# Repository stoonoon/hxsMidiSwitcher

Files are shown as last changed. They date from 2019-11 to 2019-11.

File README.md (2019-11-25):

# hxsMidiSwitcher
Simple 8 button MIDI controller for Line 6 HX Stomp using Nano clone

I'd originally shared this at https://www.basschat.co.uk/topic/338238-build-your-own-midi-controller-i-did/ but it's been pointed out (Thanks Josh!) that this would be a more sensible place for it.

It works OK and has served me fairly well over the last ~8 months I've been using it, but v2 is in the works with a touchscreen and expression pedal input...

Basic description (from that thread - although there's more info there if you want to trawl through the entire thread...

I wanted to add some more control options to my Stomp and was looking at controllers like the Morningstar MC6, but couldn't justify the £200 outlay.. so looked into making one myself - and it's turned out to be far easier and cheaper than I expected.

Total cost for all the electronics and switches is about £25 -30 depending on how confident you are at slightly fiddly soldering... the extra few quid gets you a pre-soldered microcontroller and an adaptor board with screw terminals, so the only soldering you'd need to do is for the wires to the tags on the footswitches and on the MIDI socket.

And then you'll need something to house it in. I made a 3d printed enclosure for mine, but any box you can buy/build/modify will do.

If anyone's interested in making something similar for themselves, I'd be happy to share wiring diagrams and the code I used. I'm no electronic engineer or programmer, so no doubt there's plenty of room for improvement, but I've got it to work well enough to do what I need it to, and maybe it'll work for you too? I'm happy to help with tweaking it for slightly different configurations if you'd want a different layout.

What it does:

You press a footswitch, and it sends a MIDI message. The way I have mine setup is that it either sends a MIDI PC (Program Change) message to change preset patch on my HX stomp, or a MIDI CC (Control Change) message to change any of a number of other settings or parameters. It could potentially send MIDI notes as well if you wanted to use it as a pedal keyboard to play a synth with, I suppose.

If you hold a footswitch down, it can send a different MIDI message (I only use this for activating the tuner by holding the tap tempo button so far, but it could be setup for any of the switches)

If you press more than one footswitch down at once, it can do something else again depending on which ones you press. Mine is set so that pressing 1+2 or 2+3 switches through different pages / banks of button configurations, and pressing 7 + 8 is a sort of panic mode which resets the HX stomp to preset 1, and resets the controller back to the first page.

What it can't do:

It's not programmable from the unit. To change the way the buttons are configured you need to tweak the code and then re-upload it. There's probably a more elegant way to deal with this, but it works well enough for me as is - I don't expect to need to reconfigure it very often once I've got it set up.

Right - I'm gonna stop there for now.... if no-one's interested then I'm just rambling into the void for nowt. If anyone is interested though, let us know and I can post more details. Or, if you know more than me and can spot where I've gone wrong or what I should have done better - lemme know and I'll try and improve it!

Cheers,

stoo

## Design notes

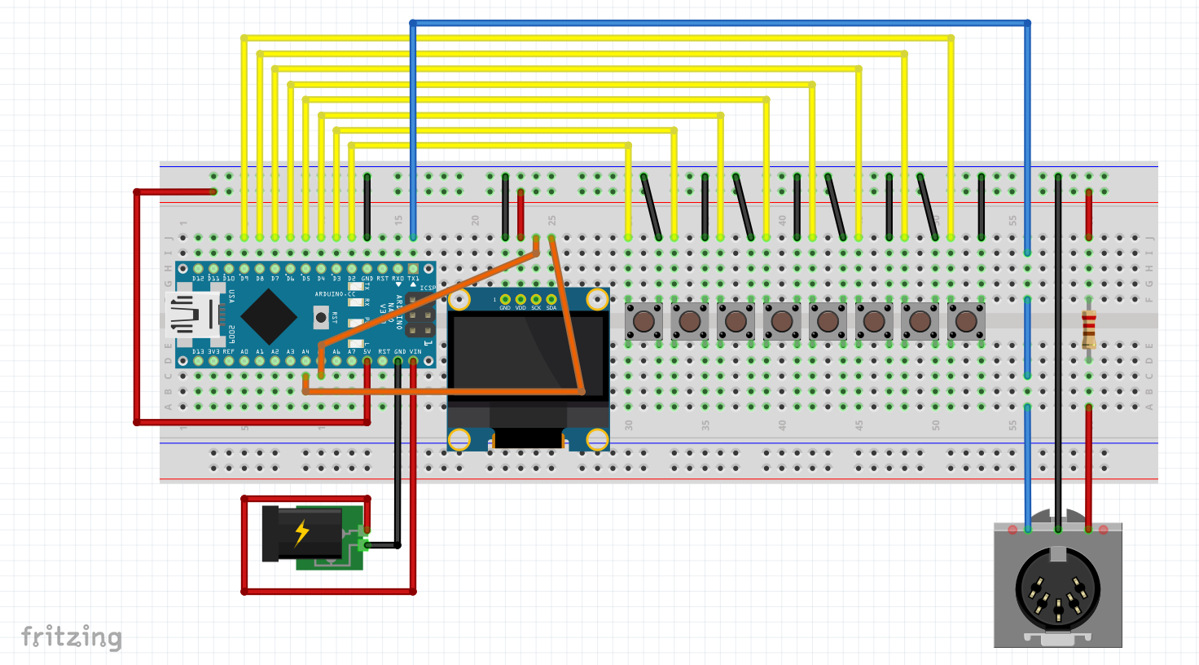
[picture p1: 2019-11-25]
breadboard.png

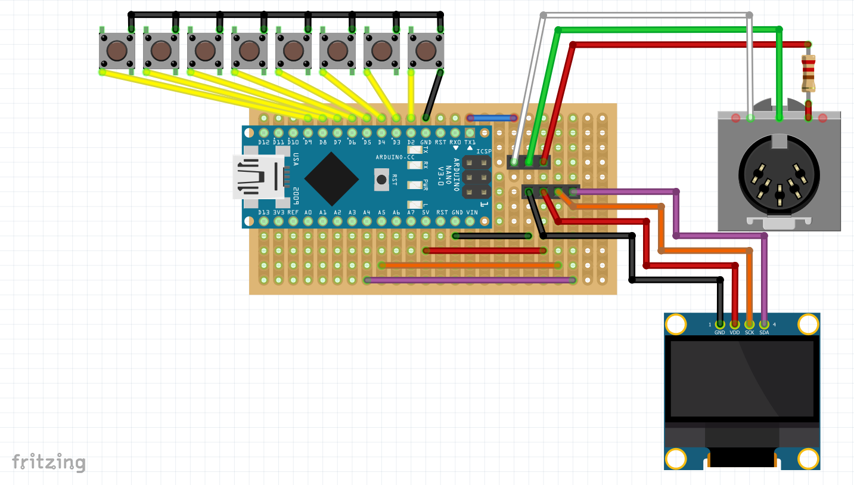
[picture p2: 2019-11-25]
stripboard.png

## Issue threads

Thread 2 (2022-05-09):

Long Press action missing?

gobbersbubbus, 2022-05-09:
Hey @stoonoon!

I was building this switcher and I don't have the function to long press the tap tempo to access the tuner?

I dont have the display so im not sure if I am missing it there, but do you have the code that allows the long press to work?

I think you can access it by pushing multiple buttons butI would prefer to have it as the long press on the tuner?

Do you have the code for that and where to drop in?

Thank you!

stoonoon, 2022-05-09:
I'm fairly sure it used to work - but at the moment I'm just on my phone and trying to reacquaint myself with years old code is a bit of a challenge....
It looks like it's at least part there, so my best guess at the moment would be that at some point I redesigned my menu page layout and missed off the case statements for long presses.... I think it's setup so case 0 to 7 were single short press actions and 8 to 15 would be long press.
Hopefully that should be enough to get you started.... If not, let us know and I'll see what I can work out when I'm next at a desktop

gobbersbubbus, 2022-05-09:
WOW THAT WAS FAST. I fully planned on waiting a week to hear from you!

That is promising, I can try to look at it, but I’m almost looking at hieroglyphics here ha ha.

This is for the Arduino Nano which I believe only has 12 digital pins? Does that mean pins 0-7 are single short press and 8-12 would be long press?

(I’m so sorry if this is a dumb question…)

Thank you

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

stoonoon, 2022-05-09:
The number for "nextCommand" isn't directly linked to the pin number on the Arduino. It's just an arbitrary variable that acts as a menu of possible midi actions... 0 to 7 on that list do happen to map to the footswitches - and they are used for the short press actions for each one. If a long press is detected, the readButtons function sets the nextCommand variable to (pin number + number of switches)... And so long presses would use the next 8 options in the "menu". Hope that makes sense.

If you look at line 311-313 you'll see:
case 7:
          MIDI.sendControlChange(53,0,1); //FS5
          break;

If you add an extra 3 lines immediately after those but instead with :

case 8:
          MIDI.sendControlChange(68,68,1); //tuner
          break;

I think that might do it....

gobbersbubbus, 2022-05-10:
I think I understand, thank you!

Sorry, last question, if I wanted to add a long press function to FS4 or FS5, where would I input those midi cc codes? Of is that possible?

Thank you!

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

stoonoon, 2022-05-10:
Do you mean long press the 4th/5th switch on your switcher?
just add another 3 lines like before but with the first line being "case 11:" for FS4 long press or "case 12:" for FS5 long press....
so, for example:

case 11: //<- this bit signifies a long press on the 4th switch
  MIDI.sendControlChange(69,9,1); //<- this is the command for previous snapshot
  break; // <- this just signifies the end of the "case" statement

case 12: // < - this bit signifies switch a long press on the 5th switch
  MIDI.sendControlChange(69,8,1); // < - this is the command for next snapshot
  break;

or did you mean to be able to use FS4 and FS5 on the stomp? In which case you could use:

case 4: // <- this means a short press on the 5th switch
  MIDI.sendControlChange(52,0,1); // <- this is the command for FS4 on the stomp
  break;

case 5: // <- this means a short press on the 6th switch
  MIDI.sendControlChange(53,0,1); // <- this is the command for FS5 on the stomp
  break;

Does that help?

stoonoon, 2022-05-25:
> Hey Stoo! I really appreciate your help with all of this! I had one more question if you had a moment… Would you have the code to add a potentiometer/expression pedal to this code? I appreciate it!

Sorry - that's not something I ever implemented on this version. I did start to add one on my other switcher - https://github.com/stoonoon/hxsMidiSwitchTouch - it was working at one point, but now mine doesn't.... I suspect it's a wiring issue, but never found it useful enough to be too bothered about troubleshooting it.

If you wanted to have a go at implementing it yourself, I *think* you might be able to get away with pasting in the "byte readPedalPos()" and "void readExpPedalCC()" functions from 07_exp_pedal.ino into your code
and then add the "readExpPedalCC();" line from 11_loop.ino into your "void loop()" function

Then you'd also need any relevant variable declarations too - should be either from the top of 08_exp_pedal.ino or from 02_globals.ino

gobbersbubbus, 2022-05-25:
You’re insane Stoo, so knowledgeable!

Okay, final question and I stop persevering you. My pot does not flow 0-100%, or 0-127, it goes from 0-100% at about 10%…

In your description I see you have a unique volume pedal and I should be able to “simplify the mapping from R2 to pd1 as they should rise proportionally to each other through the full extent of any travel…”

Would this be just adjusting the buffer value or am I way off?

Again, thank you so much!

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

stoonoon, 2022-05-25:
If you've got a linear pot which sends 0.0V for off/heeldown and 5.0V for on/toedown, then I would try replacing the readPedalPos() function with something like this:

byte readPedalPos() {
  int raw = analogRead(analogExpressionPedalPin); // get pedal position input (range 0 to 1023)
  if (raw) { // got some pedal position reading
    float pdl;
    pdl = mapf(raw, 0, 1023, 0, 127); // map pedal position into a 0-127 range for MIDI
    return byte(pdl);
  } // if(raw)
  else return 0; // no pedal position reading returned - assume heel down
}// byte readPedalPos()

Might need to add some deadzone compensation in later but hopefully that'll be closer to what you need?

gobbersbubbus, 2022-05-25:
I will monkey with it, thanks Stoo!!!!

gobbersbubbus, 2022-12-06:
Hey Stoo!Question, in your V1 code, is it possible to do a three button press? How would one code that in this?Thank you!On May 25, 2022, at 3:29 PM, Stuart Noon ***@***.***> wrote:
If you've got a linear pot which sends 0.0V for off/heeldown and 5.0V for on/toedown, then I would try replacing the readPedalPos() function with something like this:
byte readPedalPos() {
int raw = analogRead(analogExpressionPedalPin); // get pedal position input (range 0 to 1023)
if (raw) { // got some pedal position reading
float pdl;
pdl = mapf(raw, 0, 1023, 0, 127); // map pedal position into a 0-127 range for MIDI
return byte(pdl);
} // if(raw)
else return 0; // no pedal position reading returned - assume heel down
}// byte readPedalPos()
Might need to add some deadzone compensation in later but hopefully that'll be closer to what you need?

—Reply to this email directly, view it on GitHub, or unsubscribe.You are receiving this because you authored the thread.Message ID: ***@***.***>

stoonoon, 2022-12-06:
> Hey Stoo!Question, in your V1 code, is it possible to do a three button press? How would one code that in this?Thank you!

I'm honestly not sure. It wasn't something I'd considered at the time, but there is a small chance it just might work. That said - I'd be surprised if it worked reliably....

If you wanted to give it a try, the part that looks for mutiple button presses is in the readButtons() function in hxsMidiSwitcher.ino from line 157

You could try changing the part that goes

```
else if ( switchPressed[6] && switchPressed[7]) { // last two switches - reset to page 0 and patch 0
        nextCommand = pagePatchReset;
        currentPage = 0;
      }
```

to

```
else if ( switchPressed[5] && switchPressed[6] && switchPressed[7]) { // last three switches - reset to page 0 and patch 0
        nextCommand = pagePatchReset;
        currentPage = 0;
      }
```

and see how you get on. My hunch would be that if you also have 2-button combos set up for any 2 of the buttons in your 3-button combo, then you'd probably get the 2-button combo detected and the 3-button one ignored a lot of the time.
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
stoonoon, 2023-05-15:
> Your questions are my questions as well! HahaWell I appreciate your time and understand not tackling it. I’ll see what I can do! Thank you!On May 15, 2023, at 12:36 PM, Stuart Noon ***@***.***> wrote:

Good luck!

gobbersbubbus, 2024-03-29:
Hey Stoo!I had another question about the code. Would it be possible to have a way the switch behave as a toggle? For example, have one push button trigger a control change of 1 sending “velocity” of 127 then the second press send the “velocity” of 0? How would that be implemented in the code?Thank you!-Preston On May 15, 2023, at 12:47 PM, Stuart Noon ***@***.***> wrote:

Your questions are my questions as well! HahaWell I appreciate your time and understand not tackling it. I’ll see what I can do! Thank you!On May 15, 2023, at 12:36 PM, Stuart Noon @.***> wrote:

Good luck!

—Reply to this email directly, view it on GitHub, or unsubscribe.You are receiving this because you modified the open/close state.Message ID: ***@***.***>

stoonoon, 2024-03-30:
> Hey Stoo!I had another question about the code. Would it be possible to have a way the switch behave as a toggle? For example, have one push button trigger a control change of 1 sending “velocity” of 127 then the second press send the “velocity” of 0? How would that be implemented in the code?Thank you!-Preston

The button actions are hard coded according to which page you're on, so this would be an awkward one to do easily without some significant changes.

One possible workaround - if you can make do with only one toggle type button, then you could create two pages that are the same except for button x on the first page has its action in the midiSend function set to CC send with a value of 127 and then also change the menu page to 2.

On menu page 2, the action would need to be reversed so that it sends the CC value as zero and then sets the menu page pack to 1.

stoonoon, 2024-03-30:
> Hey Stoo!I had another question about the code. Would it be possible to have a way the switch behave as a toggle?

Not sure why I didn't think of this earlier, but there's no need to use multiple pages.

Instead of having something like :

case 0:
    MIDI.sendControlChange(49,0,1); //FS1
    break;

you could have something like:

case 0:
    static bool switch0NextActionIsA = true; // this will only set the variable to true on the first time the code gets here
    if (switch0NextActionIsA) { // then we do action "A" for this switch :
        MIDI.sendControlChange(69,0,1); //snapshot 1
        switch0NextActionIsA = false; // use action "B" next time
        }
    else { // then we do action "B" for this switch :
        MIDI.sendControlChange(69,1,1); //snapshot 2
        switch0NextActionIsA = true; // use action "A" next time
        }
    break;

gobbersbubbus, 2024-03-30:
Thanks for the fast response! I’ll throw it in and tinker with it!On Mar 30, 2024, at 9:22 AM, Stuart Noon ***@***.***> wrote:

Hey Stoo!I had another question about the code. Would it be possible to have a way the switch behave as a toggle?

Not sure why I didn't think of this earlier, but there's no need to use multiple pages.
Instead of having something like :
case 0:
MIDI.sendControlChange(49,0,1); //FS1
break;
you could have something like:
case 0:
static bool switch0NextActionIsA = true; // this will only set the variable to true on the first time the code gets here
if (switch0NextActionIsA) { // then we do action "A" for this switch :
MIDI.sendControlChange(69,0,1); //snapshot 1
switch0NextActionIsA = false; // use action "B" next time
}
else { // then we do action "B" for this switch :
MIDI.sendControlChange(69,1,1); //snapshot 2
switch0NextActionIsA = true; // use action "A" next time
}
break;

—Reply to this email directly, view it on GitHub, or unsubscribe.You are receiving this because you modified the open/close state.Message ID: ***@***.***>

Closed 2022-05-25.

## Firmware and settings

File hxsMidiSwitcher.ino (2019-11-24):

/*
 * ---------------------------------------------------
 * 
 * Simple 8 button MIDI controller for Line 6 HX Stomp using Nano clone
 * 
 * MIDI connectivity based on https://www.instructables.com/id/Send-and-Receive-MIDI-with-Arduino/
 * MIDI pin 4 to TX1
 * 
 * 128x64 I2C OLED - the one I used was https://smile.amazon.co.uk/gp/product/B076PL474K
 * SDA to A4
 * SCL to A5
 * 
 * 8x momentary SPST switches connected between GND and D2 - D9
 * 
 * ---------------------------------------------------
 */



#include <MIDI.h>
#include <SPI.h>
#include <Wire.h>
#include <Adafruit_GFX.h>
#include <Adafruit_SSD1306.h>


// Declaration for an SSD1306 display connected to I2C (SDA, SCL pins)
#define SCREEN_WIDTH 128 // OLED display width, in pixels
#define SCREEN_HEIGHT 64 // OLED display height, in pixels
#define OLED_RESET     -1 // Reset pin # ((was 4) or -1 if sharing Arduino reset pin)
#define OLED_ADDR 0x3C  // address of my 128x64 OLED
Adafruit_SSD1306 display(SCREEN_WIDTH, SCREEN_HEIGHT, &Wire, OLED_RESET);

// error blink codes
#define ERR_DISP_ALLOC 3 // display allocation error

static const unsigned ledPin = LED_BUILTIN; // use onboard LED as activity indicator
static const byte switchPin[] = {2,3,4,5,6,7,8,9}; // pins for footswitch inputs
static const byte switchCount = 8; // number of footswitches used
static bool switchPressed[switchCount]; // current state of footswitches
static bool switchLastState[switchCount]; //previous state of footswitches (used for long press detection)
static unsigned long lastPressMillis[switchCount]; // when the last button press was detected
static unsigned long lastReleaseMillis[switchCount]; // when the last button was released

// Created and binds the MIDI interface to the default hardware Serial port
MIDI_CREATE_DEFAULT_INSTANCE();


void errBlink(int errCode) {
  byte blinkTime = 200; // duration for each blink
  byte blinkGap = 200; // gap between each blink
  int burstWait = 1000; // wait time between bursts 
  for (;;) { // loop forever
    for (int i = 1; i <= errCode; i++) {
      digitalWrite(ledPin,HIGH);
      delay(blinkTime);
      digitalWrite(ledPin,LOW);
      delay(blinkGap);
    }
    delay(burstWait);
  }
} // end of errBlink()


void setup() {
  pinMode(ledPin, OUTPUT);  // setup activity LED pin for output

  MIDI.begin(MIDI_CHANNEL_OMNI);  // Listen to all incoming messages
  
 // SSD1306_SWITCHCAPVCC = generate display voltage from 3.3V internally
 if(!display.begin(SSD1306_SWITCHCAPVCC, OLED_ADDR)) { // Address 0x3C for my 128x64 variant
   errBlink(ERR_DISP_ALLOC);
  }

  // Show initial display buffer contents on the screen --
  // the library initializes this with an Adafruit splash screen.
  display.display();
  delay(500); // Pause for 0.5 seconds
  display.setTextSize(1);      // Normal 1:1 pixel scale
  display.setTextColor(WHITE); // Draw white text
  display.setCursor(0, 0);     // Start at top-left corner
  display.cp437(true);         // Use full 256 char 'Code Page 437' font
  display.clearDisplay();
  
  // Initialise switches and related variable arrays
  for (int i=0;i<switchCount;i++) { 
    pinMode(switchPin[i], INPUT_PULLUP); // add pullup resistors to all footswitch input pins
    switchPressed[i] = false; //initialise switch state
    switchLastState[i] = false; //initialse last switch state
    lastReleaseMillis[i] = millis(); // initialise time switch last released
    lastPressMillis[i] = lastPressMillis[i] -1; // initialise time switch last pressed
  }

} // end of setup


void loop() {
  readButtons();
  displayUpdate();
  midiSend();
} // end of loop

/*
 * ----------------------------------------
 * 
 * Input related declarations and functions
 * 
 * ----------------------------------------
 */


static const bool switchDown = LOW; // because we are using pullup resistor and switch to GND
static const byte debounceTime = 20; // after processing a button press, ignore further input for some milliseconds
static const byte debounceDelay = 5; // amount of time to wait before retesting debounceTime
static const int longPressTime = 1000; // how long a switch has to be held to count as a long press
static int switchPressedCounter = 0; // how many switches are currently pressed
static byte nextCommand = -1; // most important pending action - the switch that was last pressed, or other command via multi or long press
static byte lastCommand = -1; // last command sent (used for display confirmation)
static unsigned long commandMillis = millis(); // the time that nextCommand was last set - ie the last switch to be pressed
static const byte pageDnCmd = 5*switchCount + 1;
static const byte pageUpCmd = 5*switchCount + 2; 
static const byte pagePatchReset = 5*switchCount + 3; 
static const byte tunerCmd =  5*switchCount + 4;

static byte currentPage = 0; // the current page / bank to be displayed
static const byte pageCount =1; // how many pages we have configured

void readButtons() {  
  switchPressedCounter = 0;
  for (int i=0;i<switchCount;i++) {
    switchPressed[i] = ( digitalRead(switchPin[i]) == switchDown ); // set array element to true if switch is currently pressed, or false if not
    if (switchPressed[i] != switchLastState[i]) { //potential press or release detected
      if (switchPressed[i]) { // potential new press detected
        if ( millis() > (lastPressMillis[i] + debounceTime) ) { // genuine press and not switch bounce
          lastPressMillis[i] = millis();
          switchLastState[i] = true;
          nextCommand = i;
          commandMillis = millis();          
        }
      }
      else if (!switchPressed[i]) { //potential switch release detected
        if ( millis() > (lastReleaseMillis[i] + debounceTime ) ) { // genuine release and not switch bounce
          lastReleaseMillis[i] = millis();
          switchLastState[i] = false;
        }
      }
    }
    if (switchPressed[i]) {
      switchPressedCounter++;  //increment counter used to check multiple presses      
      if (  millis() > (lastPressMillis[i] + longPressTime)  ) { // long press detected
        lastPressMillis[i] = millis(); // reset timer so it doesn't re-trigger every loop
        nextCommand = i + switchCount; // use the next n numbers as a second bank of commands representing long press actions        
      }
    }
  }
  static bool comboActive = false; // remembers whether multiple presses were detected to avoid re-triggering every loop
  if (switchPressedCounter > 1 ) { // multiple presses detected
    if (!comboActive) {
      comboActive = true;
      if ( switchPressed[0] && switchPressed[1]) { // first two switches -> Page Down
        nextCommand = pageDnCmd;
        changePageDown();
        }
      else if ( switchPressed[1] && switchPressed[2]) { // second two switches -> Page Up
        nextCommand = pageUpCmd;
        changePageUp();
        }
      else if ( switchPressed[2] && switchPressed[3]) { // 3rd 2 switches -> tuner
        nextCommand = tunerCmd;
        }
        
          
      else if ( switchPressed[6] && switchPressed[7]) { // last two switches - reset to page 0 and patch 0
        nextCommand = pagePatchReset;
        currentPage = 0;
      }
      }
    }
  else {
    comboActive = false; // we can reset this as no more than one switch currently pressed
  }
  lastCommand = nextCommand;
} // end of read_buttons()

void changePageUp() {
  currentPage++;
  if (currentPage >= pageCount) { // we have gone past the last page
    currentPage = 0; // reset to first page
  }
}

void changePageDown() {
  currentPage--;
  if (currentPage > pageCount) { // we have scrolled back past the first page
    currentPage = (pageCount -1); // reset to last page
  }
}




/*
 * 
 * Display related functions
 * 
 */


void invSelection(int i=(lastCommand+1)) {
  if (lastCommand == i) { // highlight the last switch pressed by inverting the colours
    display.setTextColor(BLACK, WHITE);
  }
  else {
    display.setTextColor(WHITE, BLACK);
  }
}


void displayLine(const __FlashStringHelper *str0, const __FlashStringHelper *str1, const __FlashStringHelper *str2, const __FlashStringHelper *str3, int startBtn) {
display.print(F("|"));
invSelection(0+startBtn);
display.print(str0);
invSelection();
display.print(F("|"));
invSelection(1+startBtn);
display.print(str1);
invSelection();
display.print(F("|"));
invSelection(2+startBtn);
display.print(str2);
invSelection();
display.print(F("|"));
invSelection(3+startBtn);
display.print(str3);
invSelection();
display.println(F("|"));
}


void displayUpdate(void) { // maybe change this to put labels in arrays, but this will do for now
  display.clearDisplay();
  display.setCursor(0, 0);     // Start at top-left corner
  switch (currentPage) {
    case 0:
      displayLine(F("SNAP"),F("SNAP"),F("SNAP"),F("FS5 "),4);
      displayLine(F("SHOT"),F("SHOT"),F("SHOT"),F(" /  "),4);
      displayLine(F(" 1  "),F(" 2  "),F(" 3  "),F(" UP "),4);   
      display.println(F("---------------------"));
      displayLine(F("    "),F("    "),F("    "),F("FS4 "),0);
      displayLine(F("FS1 "),F("FS2 "),F("FS3 "),F(" /  "),0);
      displayLine(F("    "),F("    "),F("    "),F("DOWN"),0);
      break;
   
    case 1:
      displayLine(F("FS4 "),F("FS5 "),F("TAP "),F("    "),4);
      displayLine(F(" /  "),F(" /  "),F("TMPO"),F("TUNE"),4);
      displayLine(F("DOWN"),F(" UP "),F("    "),F("    "),4);
      display.println(F("---------------------"));
      displayLine(F("    "),F("    "),F("    "),F("NEXT"),0);
      displayLine(F("FS1 "),F("FS2 "),F("FS3 "),F(" FS "),0);
      displayLine(F("    "),F("    "),F("    "),F("MODE"),0);   
      break;
 
    }
  display.display();
}

/*
 * 
 * MIDI output related functions
 * 
 */


void midiSend() {
  // do something
  if (nextCommand >=0) {
    if (nextCommand == pagePatchReset) { // SW7 & SW8 should reset page and patch to 0 regardless of which page/patch currently active
      MIDI.sendProgramChange(0,1);
    }
    else if (nextCommand == tunerCmd) {
    MIDI.sendControlChange(68,68,1); //tuner
        }
        
    else {
    switch(currentPage) {
      case 0: // menu page 0 (1 of 2)
       switch(nextCommand) {
        case 0:
          MIDI.sendControlChange(49,0,1); //FS1
          break;
        case 1:
          MIDI.sendControlChange(50,0,1); //FS2
          break;
        case 2:
          MIDI.sendControlChange(51,0,1); //FS3
          break;
        case 3:
          MIDI.sendControlChange(52,0,1); //FS4
          break;
        case 4:
          MIDI.sendControlChange(69,0,1); //snapshot 1
          break;
        case 5:
          MIDI.sendControlChange(69,1,1); // snapshot 2
          break;
        case 6:
          MIDI.sendControlChange(69,2,1); //snapshot 3
          break;
        case 7:
          MIDI.sendControlChange(53,0,1); //FS5
          break;        
        
        } // end of menu page 0
        break;
      case 1: // menu page 1 (2 of 2)
       switch(nextCommand) {
        case 0:
          // -> FS1
          MIDI.sendControlChange(49,0,1); //FS1
          break;
        case 1:
          // -> FS2
          MIDI.sendControlChange(50,0,1); //FS2
          break;
        case 2:
          // -> FS3
          MIDI.sendControlChange(51,0,1); //FS3
          break;
        case 3:
          // -> PRESET MODE PAGE
          MIDI.sendControlChange(71,4,1); //next footswitch mode (temp functionality until I work out if I can change currentPage while in switch block)
          break;
        case 4:
          MIDI.sendControlChange(52,0,1); //FS4
          break;
        case 5:
          MIDI.sendControlChange(53,0,1); //FS5
          break;
        case 6:
          MIDI.sendControlChange(64,64,1); //tap tempo
          break;
        case 7:
          MIDI.sendControlChange(68,68,1); //tuner
          break;
        } // end of menu page 1
        break;
      
      
        break;
    } // end of outer nested switch case
}      
    nextCommand = -1; // re-initialise this so we don't send the same message repeatedly
  }
} // end midisend
